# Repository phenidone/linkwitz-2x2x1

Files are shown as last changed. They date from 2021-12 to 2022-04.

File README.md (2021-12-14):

# Linkwitz (2x2).1

This is a PCB design for an analogue active crossover system.  It implements the basic set of active filters required
to build a 2.1 speaker system with 2-way main speakers and a single subwoofer.

The board fits in the standard/cheap 100x100mm PCB-prototyping form-factor.  It is mostly surface-mount, except it supports 
DIP op-amps and provides through-hole options for the larger capacitors.

## Filtering

The board implements:
* Input filtering and buffered stereo volume control
* A subwoofer signal chain, composed of:
  * Channel mixer
  * Plugin port for an external filter, e.g. room-correction notch
  * Linkwitz Transform
  * 2nd-order Butterworth subsonic filter
  * 4th-order Linkwitz-Riley low-pass
  * Gain control pot
* A midrange signal chain for each channel, composed of:
  * Plugin port for an external baffle-step compensation filter
  * 4th-order Linkwitz-Riley high-pass
  * 4th-order Linkwitz-Riley low-pass
  * Gain control trimpot
* A tweeter signal chain for each channel, composed of:
  * 4th-order Linkwitz-Riley high-pass
  * Plugin port for an external all-pass filter
  * Gain control trimpot

Room measurements will be necessary before performing component selection on the Linkwitz Transform.

## I/O

The board accepts a stereo line-level signal and produces 5 line level signals:
* Subwoofer
* Left mid-woofer
* Right mid-woofer
* Left tweeter
* Right tweeter

## Power

The board requires a dual-rail regulated DC supply, 12-15V.  Use screw terminals.

## Components

You will need 13 dual op-amp DIPs, probably NE5532.  You can use TL072 for the subwoofer chain, particularly if you need to 
save power and/or are building relatively high-impedance Linkwitz-Transform and Subsonic Filters because you couldn't find 
large enough capacitors...

Filter capacitors should be film type, with surface-mount capacitors intended to be polyphenylene sulfide (PPS) e.g. 
Panasonic ECHU(X), with at most 2% tolerance.  Filter resistors should be thin-film metal with 1% or better tolerance, 
though thick-film metal resistors are acceptable in the subwoofer section outside the filters.

Bypass capacitors are X7R ceramic, the main filter caps at the power port can be tantalum or electrolytic and as large as 
you like as long as they fit.

All surface-mount resistors and non-filter capacitors are 0805 footprint.  Filter capacitors are multi-footprint, with 
1210/1206 for most and through-hole lead-pitch options between 5mm and 15mm for the larger ones where MKT/PP/PET 
rectangular types will be required.  In some cases, up to 3 footprints are provided in series/parallel to allow you to make 
up precise values by combination; 0R bridges will be required to fill in unused resistor footprints.

## TRL and Regulatory

This design has been prototyped and unit-tested as working in a benign environment.  It has not faced MTBF validation 
or environmental (thermal+vibration) testing.

This is a PELV (Protected Extra Low Voltage, per IEC-60950) circuit, which should remain safe except in cases of a ground 
fault in the power supply external to this PCB.  Similarly, this is a low-frequency audio application with no switching 
power supplies and no clocks, therefore there are believed to be no regulatory requirements relating to EMI in most 
jurisdictions.  It has received no third-party certification or testing.

## License

This hardware design is (C) 2021 William Brodie-Tyrrell and is licensed under the CERN OHL; see cern_ohl_v_1_2.pdf

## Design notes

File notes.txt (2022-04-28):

Linkwitz-Riley rules:
f = 1/(2^1.5 pi R C)
R = 1/(2^1.5 pi f C)

lowpass uses 4R and 6C, 2x1u
highpass uses 6R and 4C, 2x1u
... channel.
Total 20R and 20C for stereo slope-pair

for bookshelves:
100Hz: 100n and 11253, 12k=94Hz, 11k=102Hz
75Hz: 100n and 15k
63Hz: 100n and 18k *
47Hz: 100n and 24k
2000Hz: 22n and 2550R/2490R *

Linkwitz Transform
31Hz, Q=0.707 to 20Hz, Q=0.73

THIS ONE:
R1=13.4k = 12k+1.2k+220
R2=45.6k = 39k+5.6k+1k
R3=32.1k = 27k+4.7k+390
C1=1.48u = 1.5u
C2=100n, 2 of
C3=615n = 560n+47n+10n

2nd order Butterworth for LF highpass...
for 15Hz corner
C=200n, R=39k (14Hz)
C=560n, R=12k (17Hz)
needs 2 of C and 3 of R

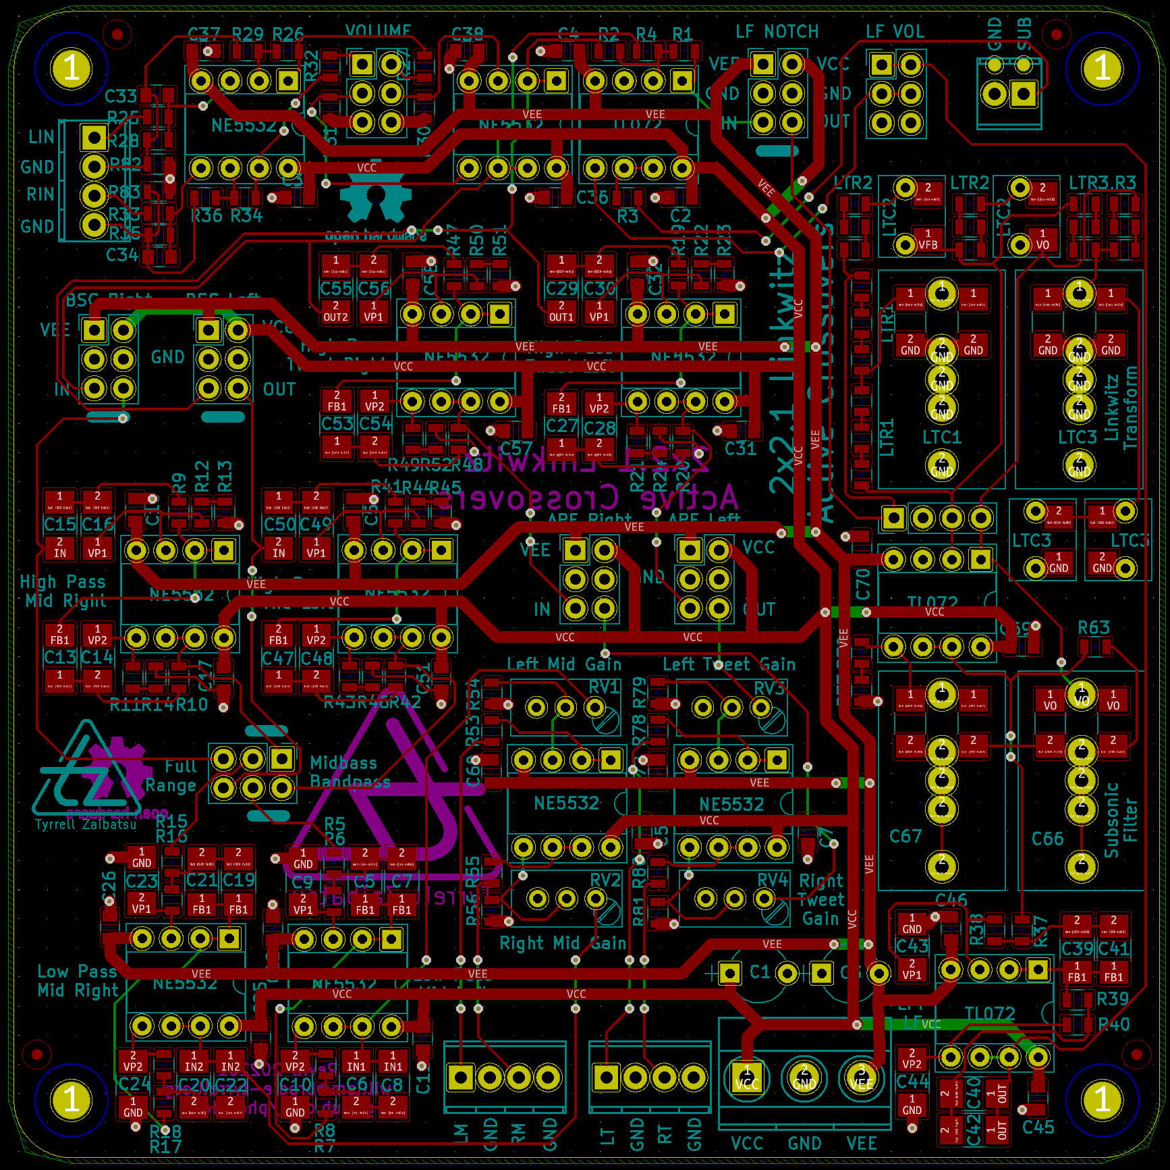
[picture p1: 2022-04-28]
xover-layout.png

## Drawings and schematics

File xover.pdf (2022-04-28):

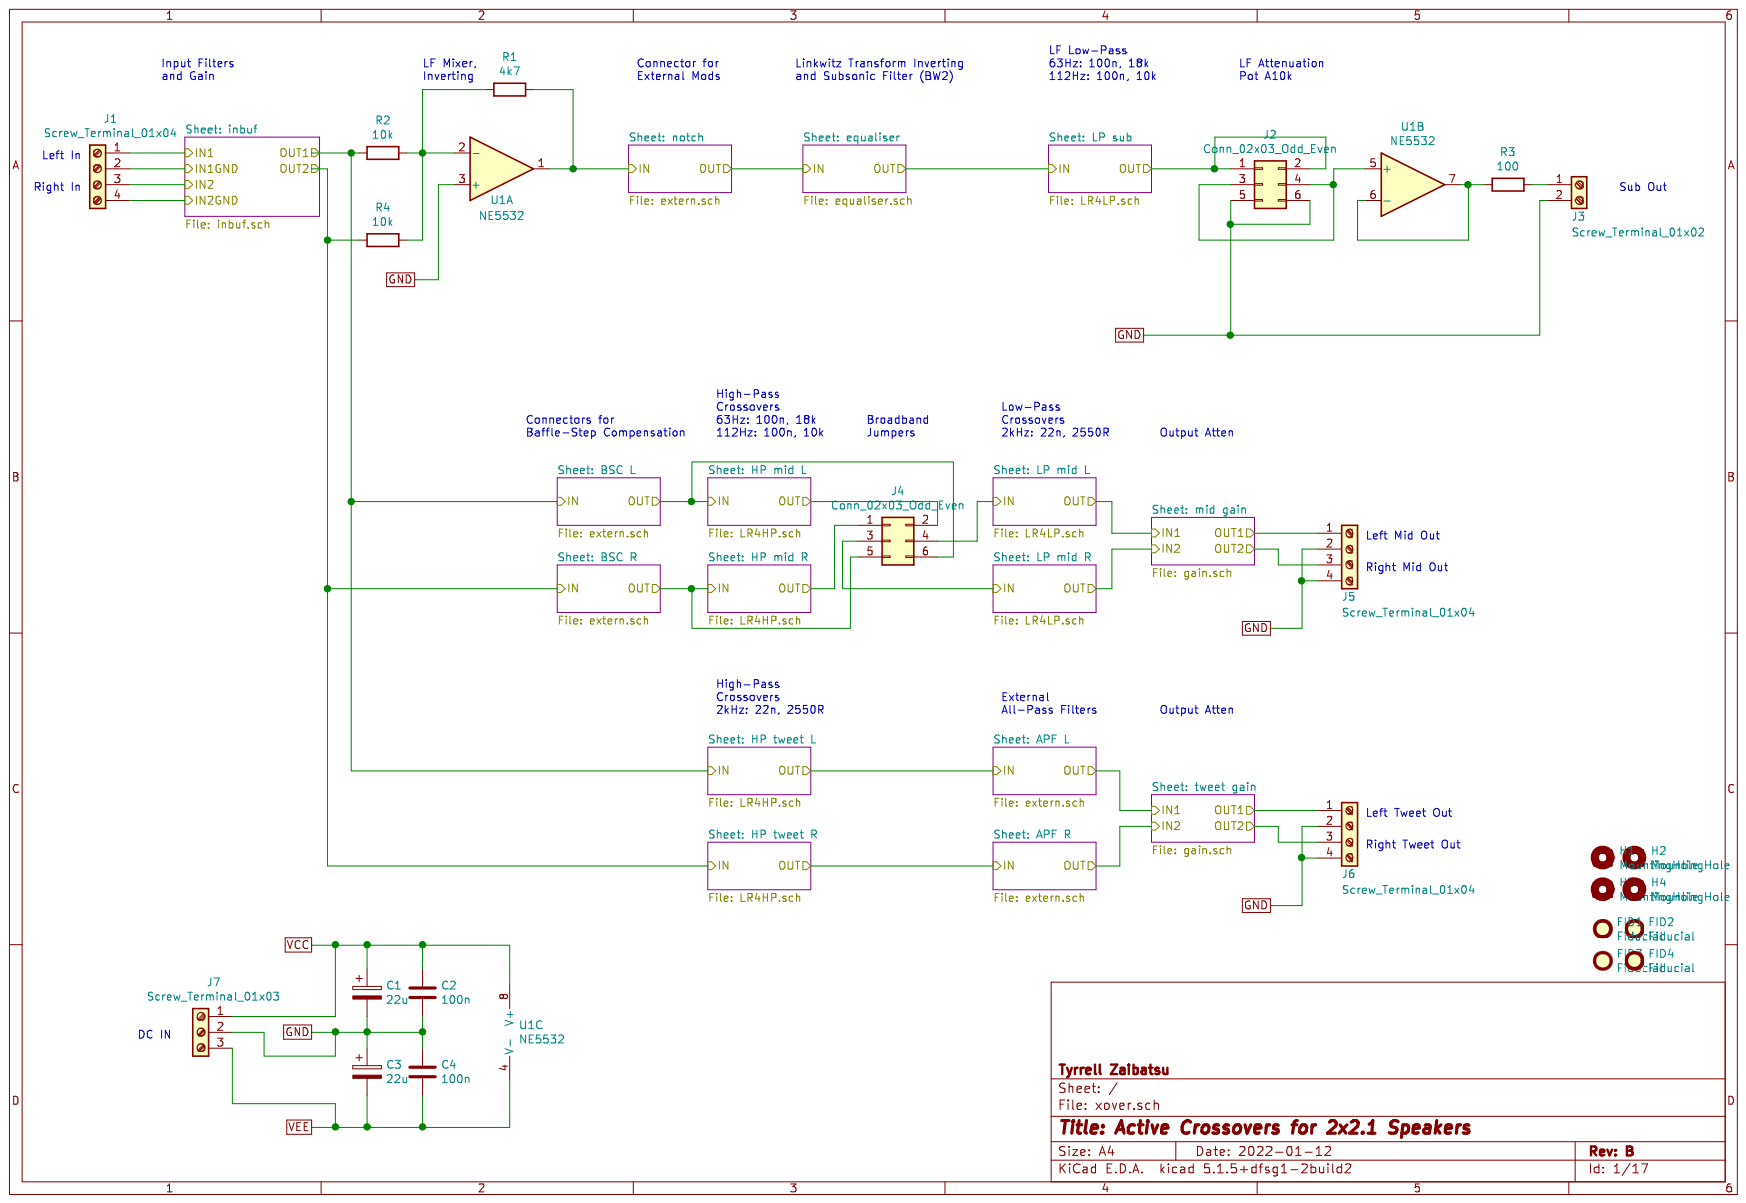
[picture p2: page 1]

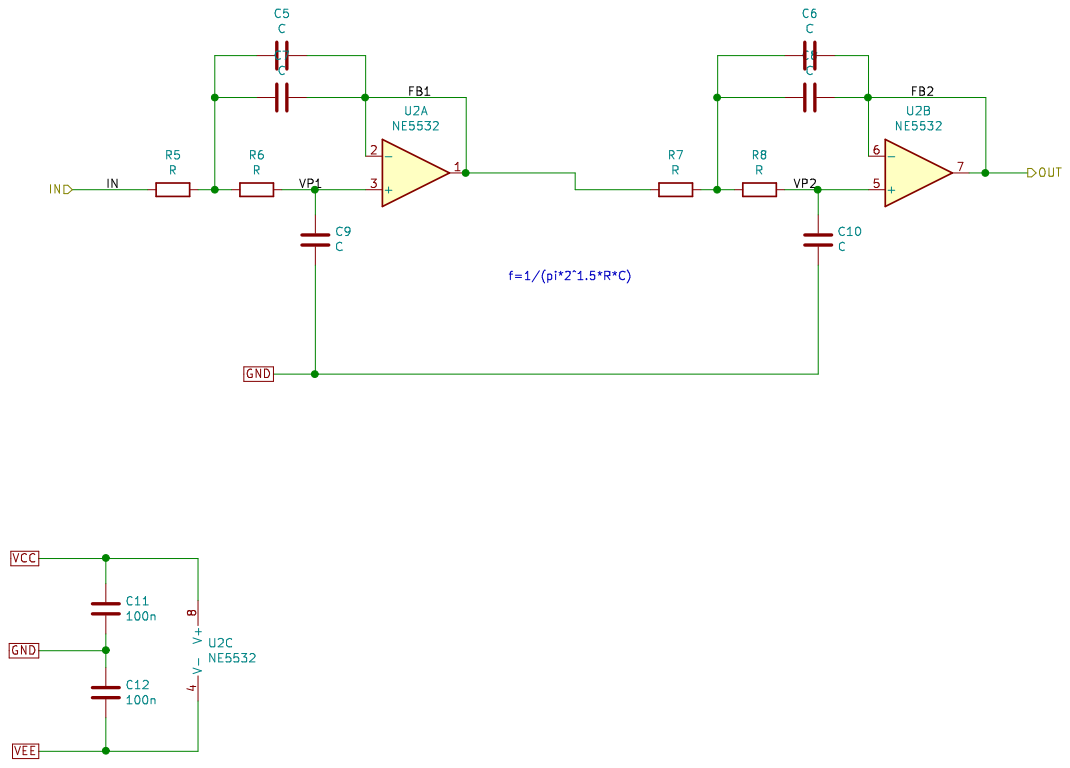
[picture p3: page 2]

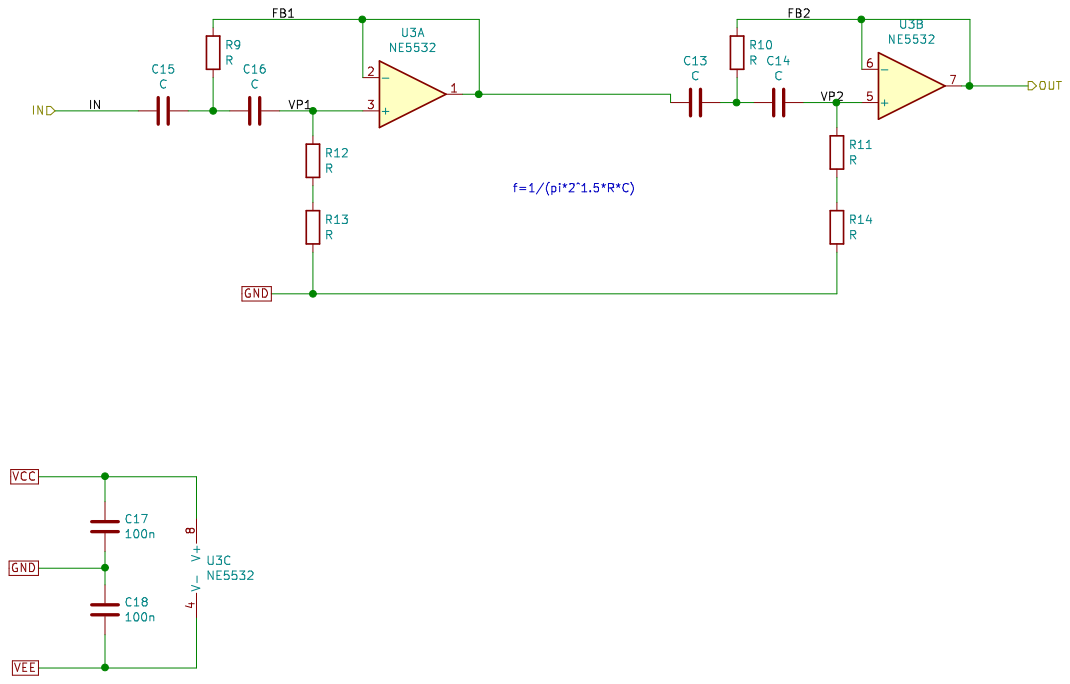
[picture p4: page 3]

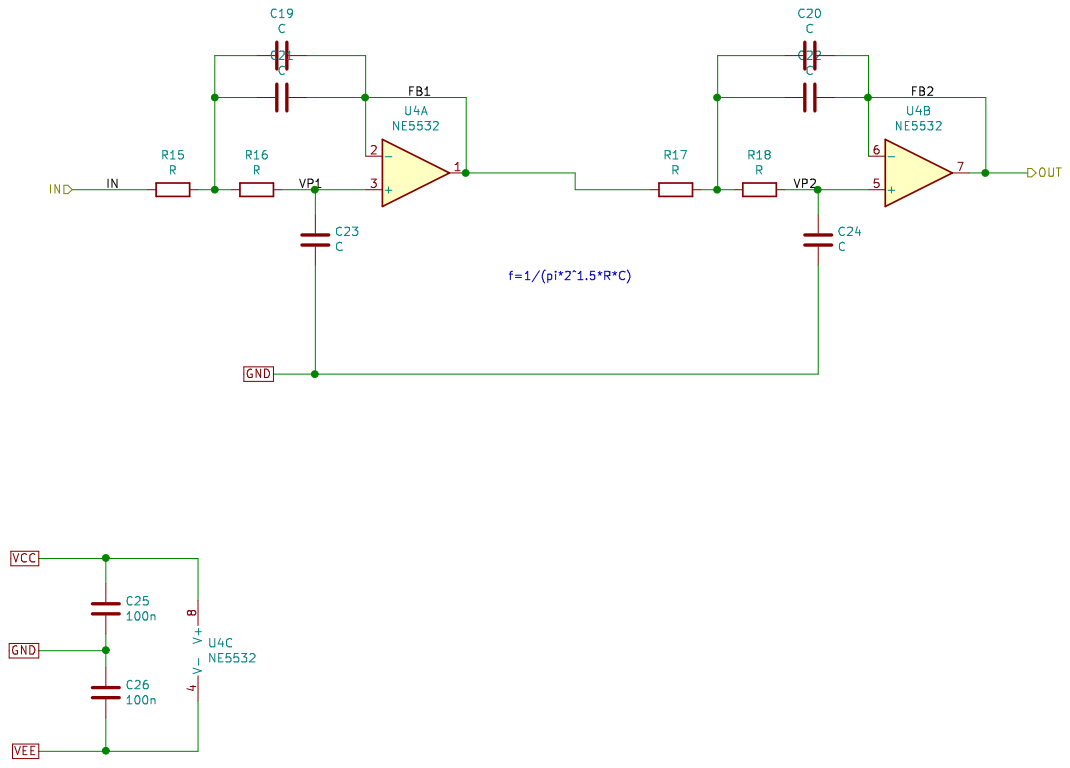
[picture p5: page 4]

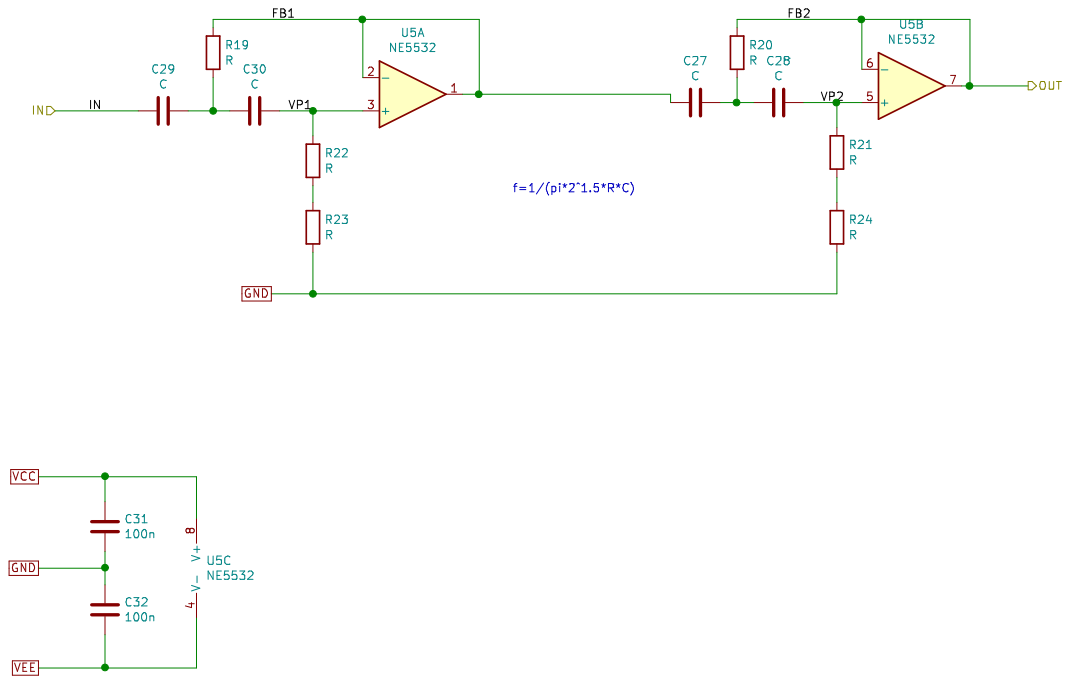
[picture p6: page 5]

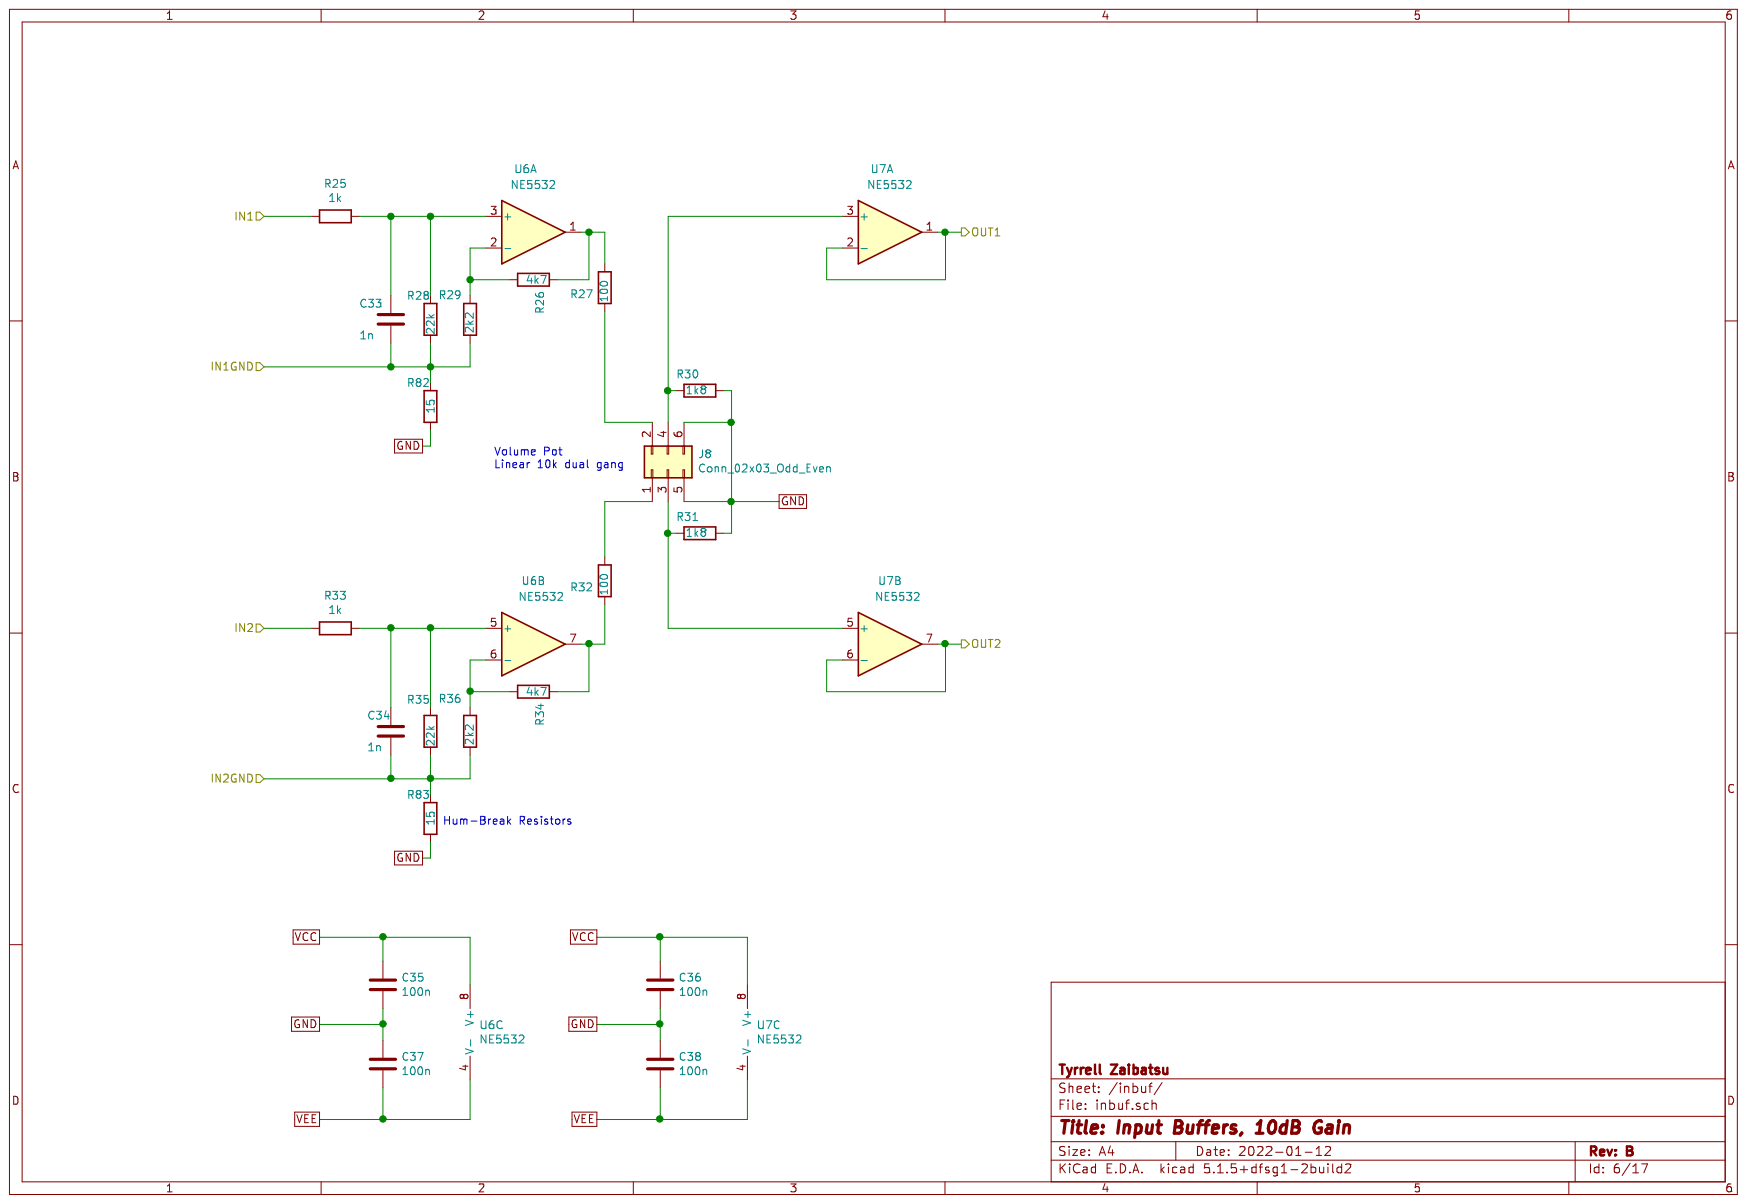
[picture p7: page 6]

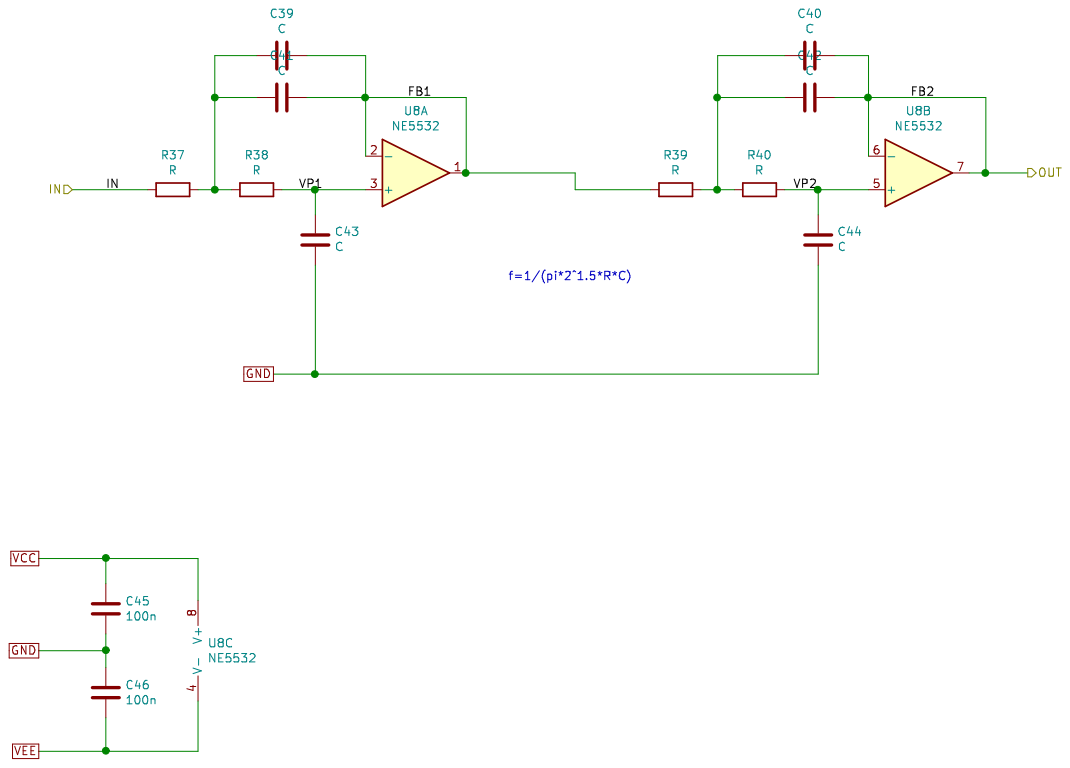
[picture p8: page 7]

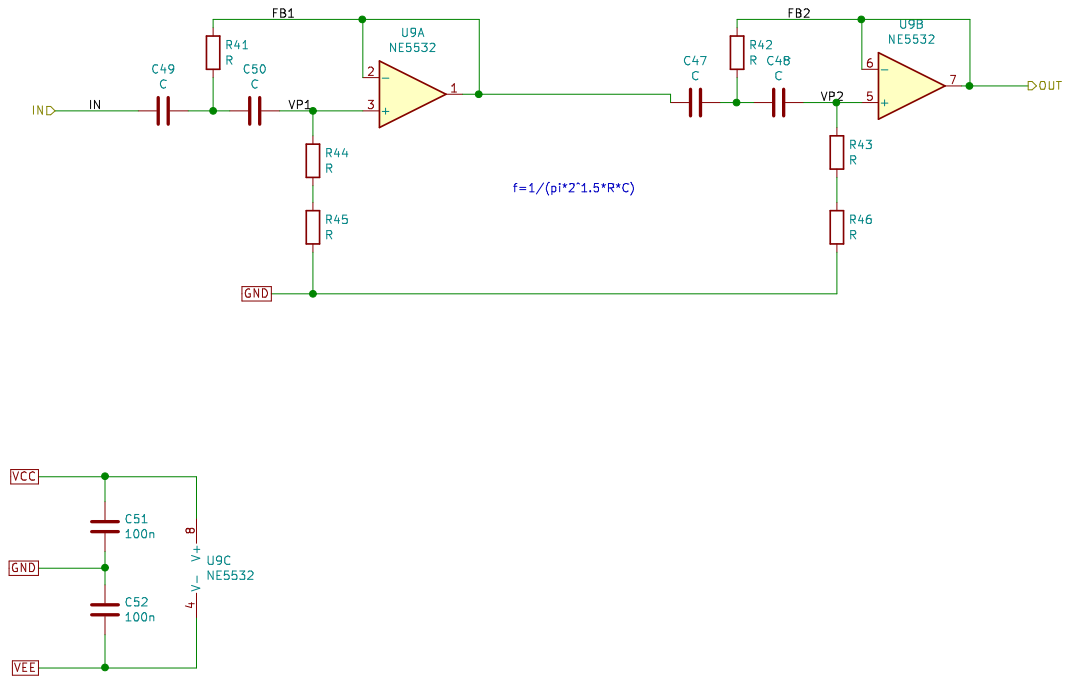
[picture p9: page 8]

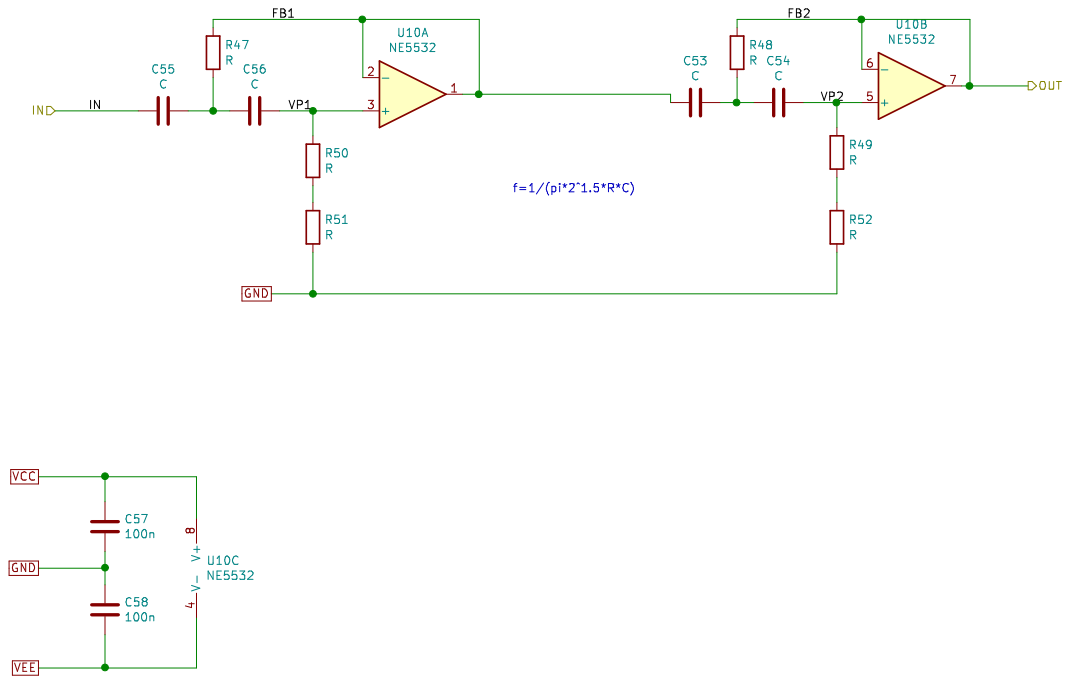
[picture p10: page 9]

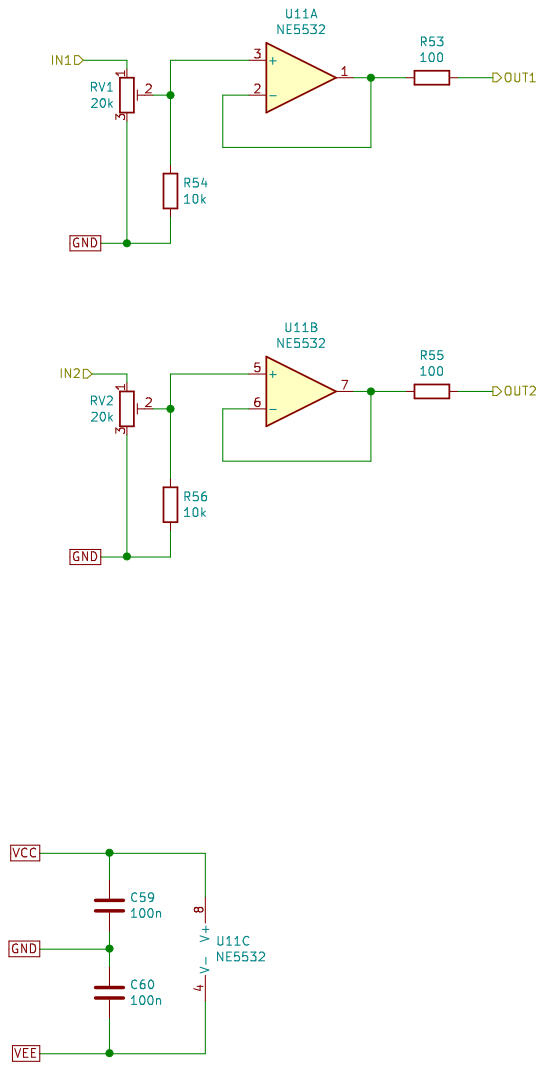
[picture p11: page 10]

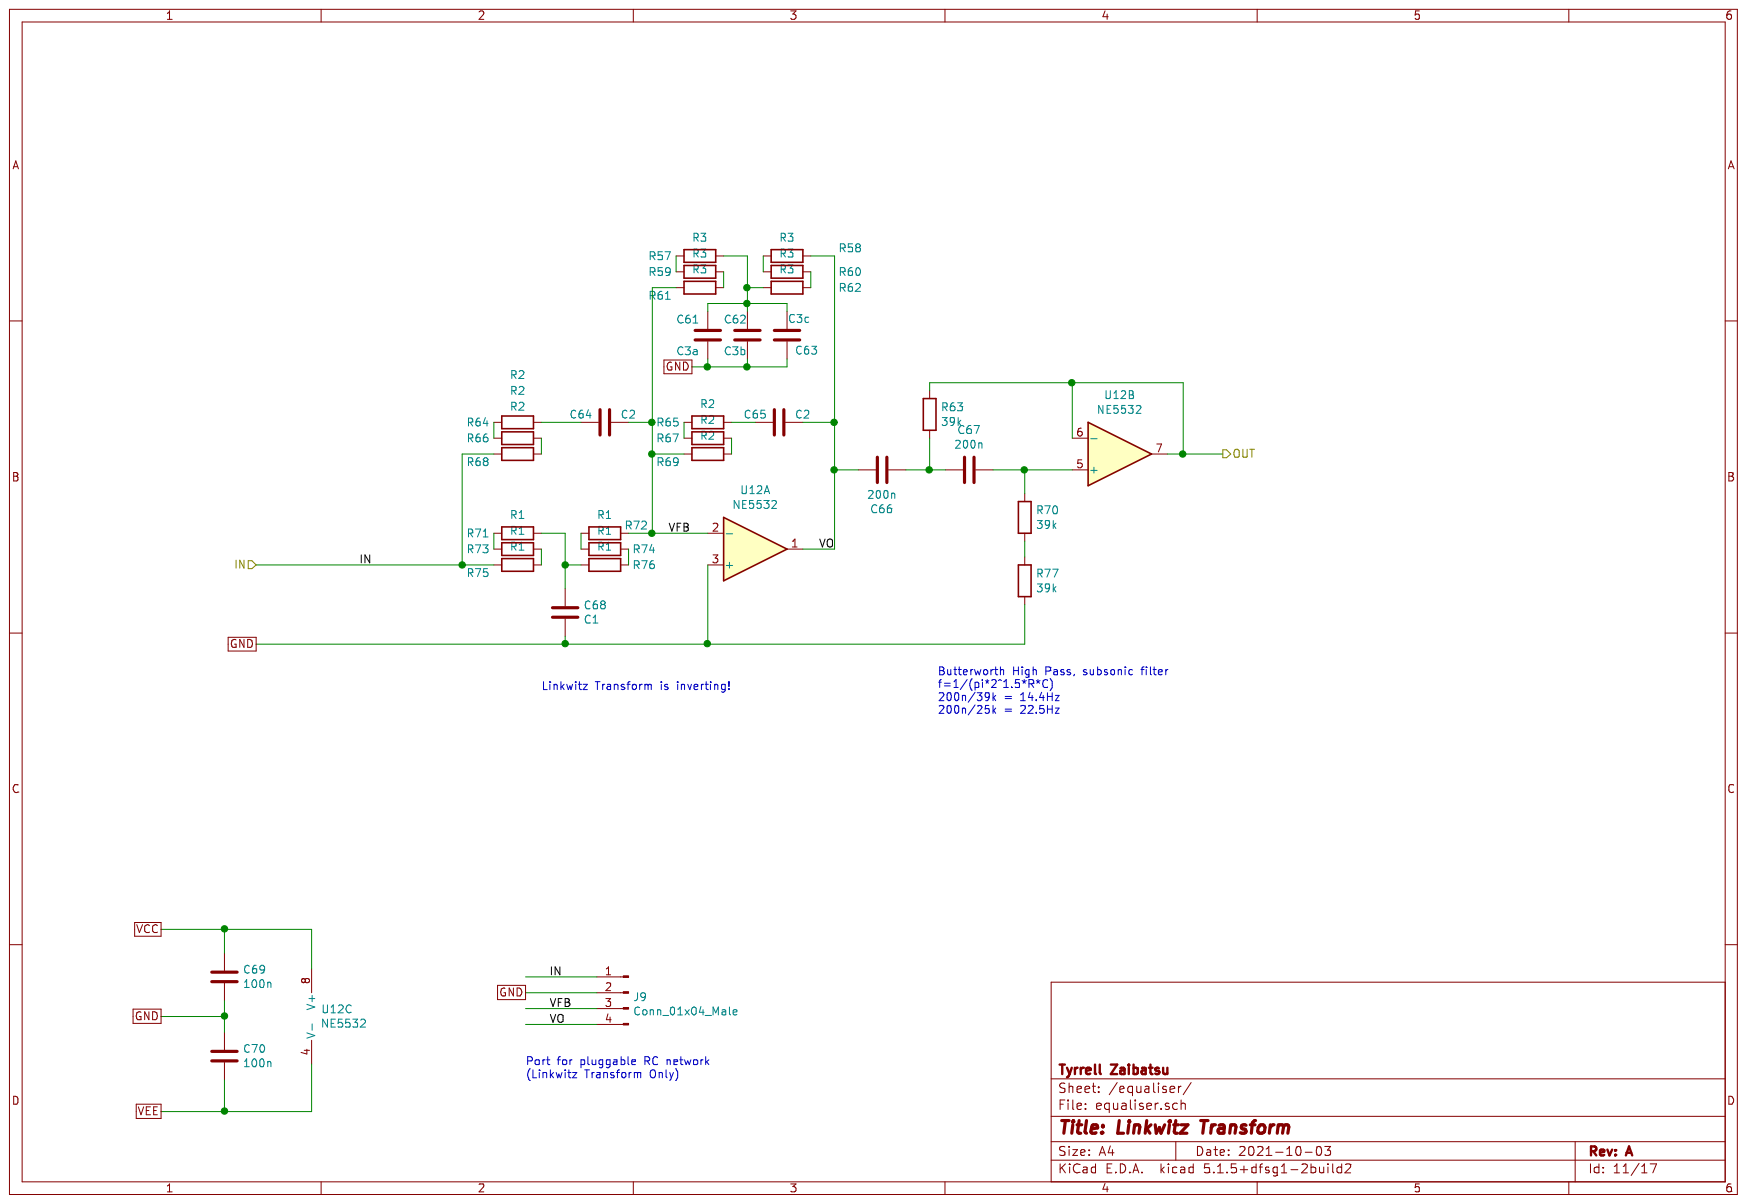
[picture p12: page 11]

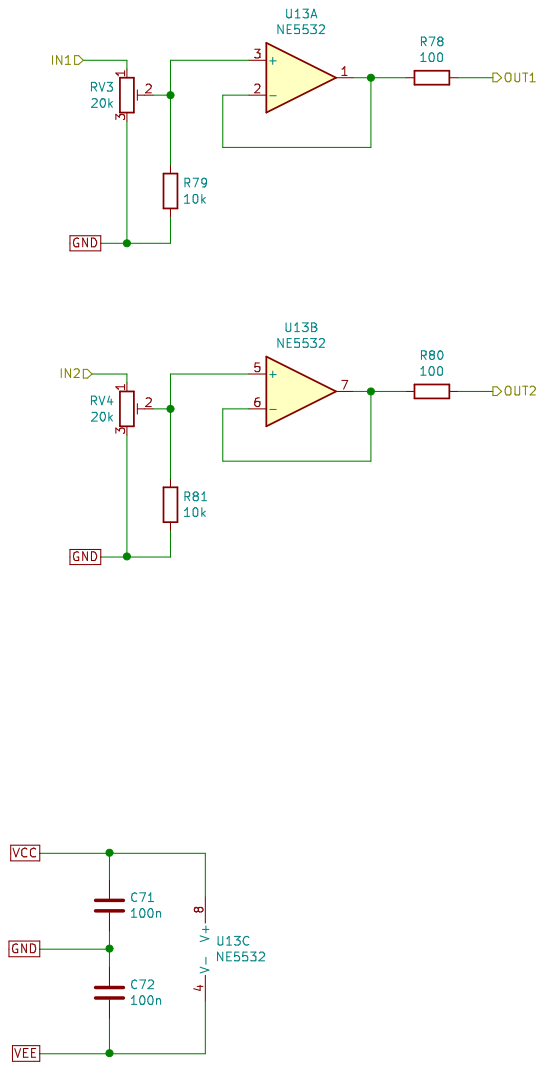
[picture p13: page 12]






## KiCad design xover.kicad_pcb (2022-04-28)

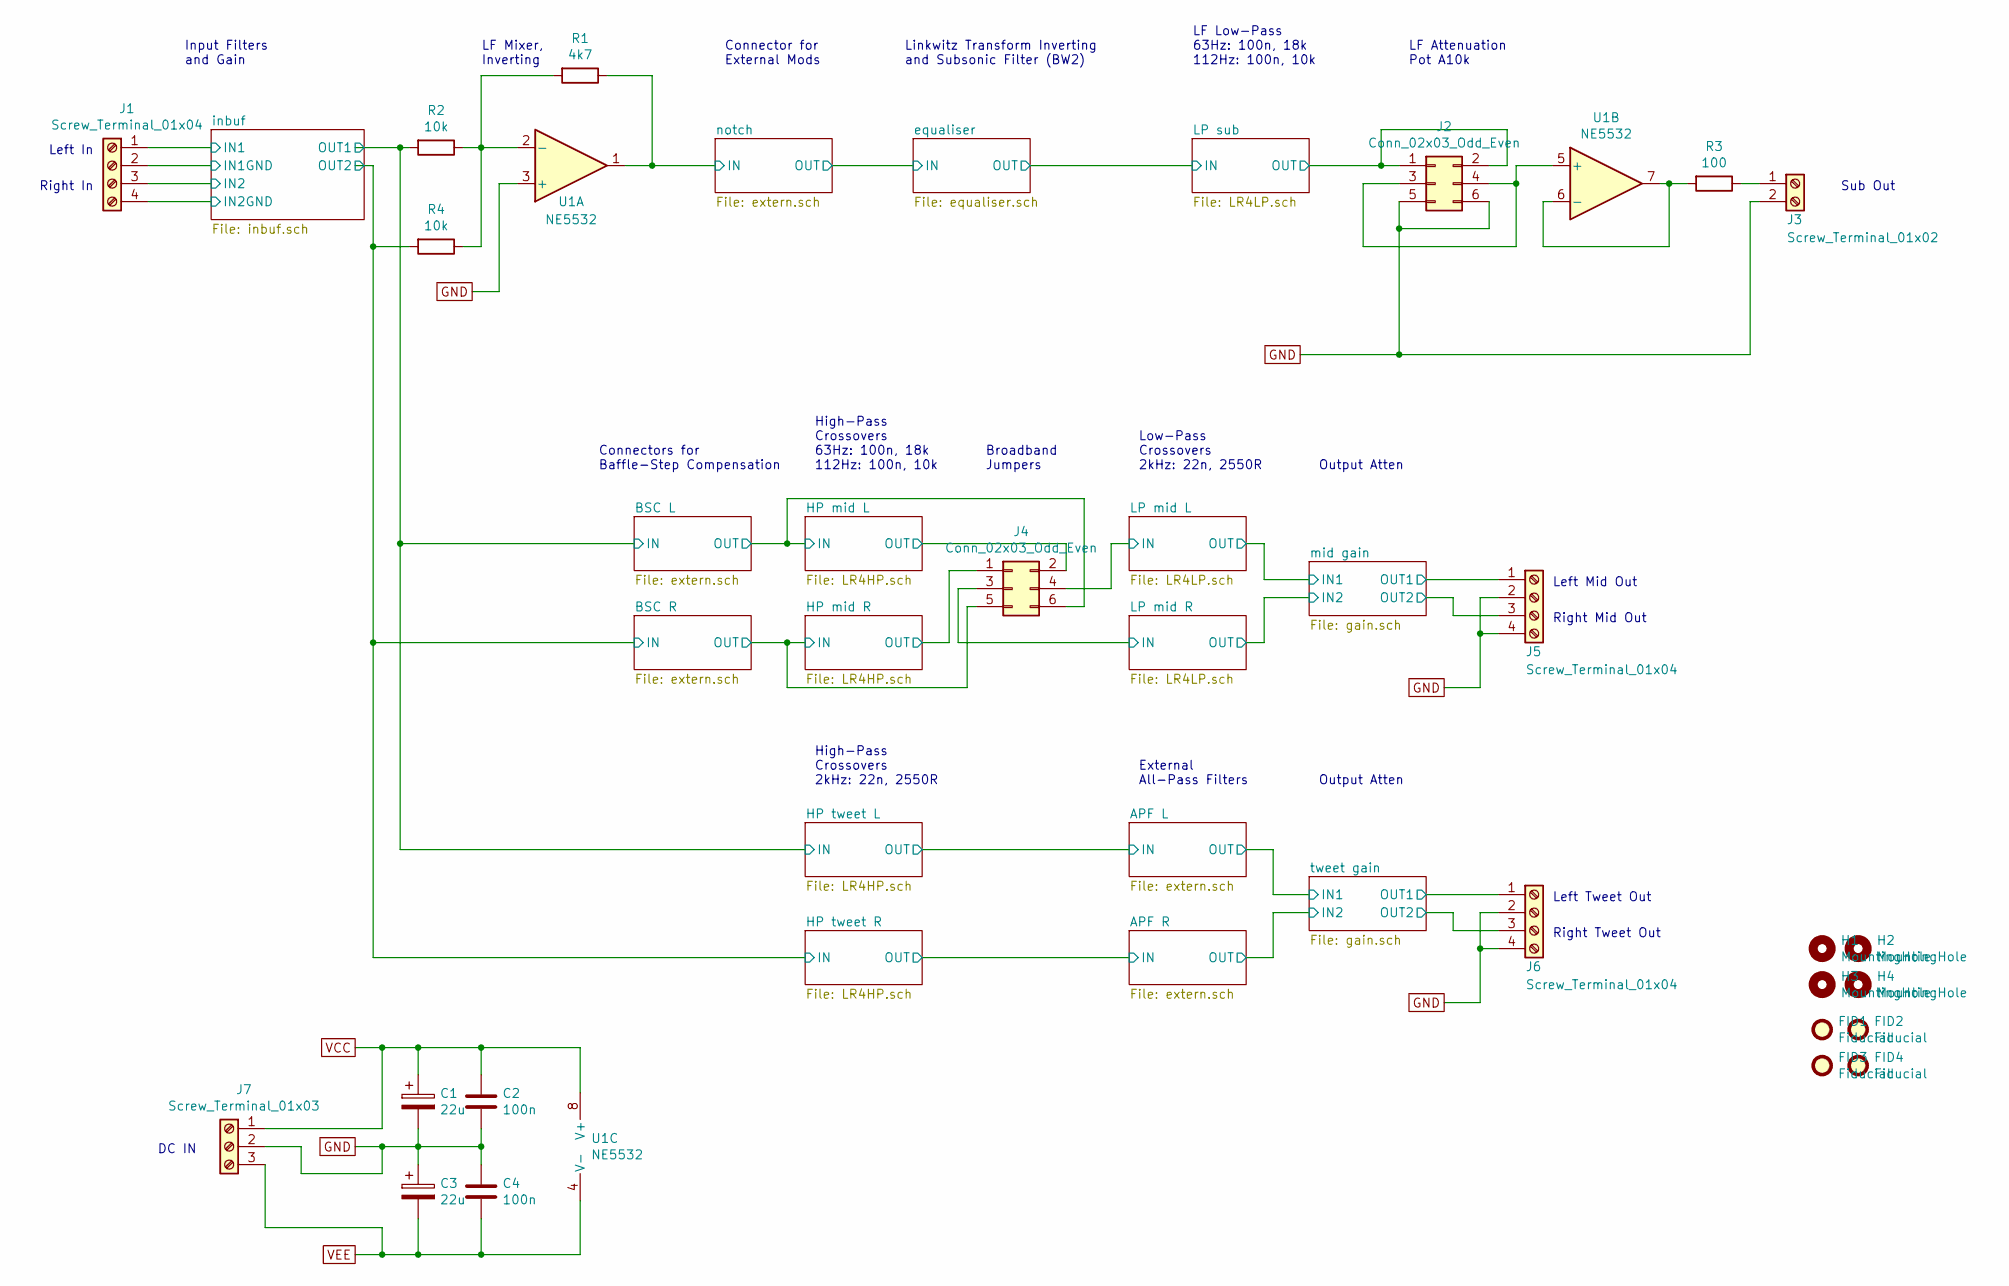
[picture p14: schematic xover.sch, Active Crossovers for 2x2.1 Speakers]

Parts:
C1, C3: 22u; CP_Radial_Tantal_D5.0mm_P5.00mm
C2, C4: 100n; C_0805
FID1, FID2, FID3, FID4: Fiducial; Fiducial_1mm_Dia_2.54mm_Outer_CopperTop
H1, H2, H3, H4: MountingHole; MountingHole_3.2mm_M3
J1, J5, J6: Screw_Terminal_01x04; TerminalBlock_Phoenix_MPT-2.54mm_4pol
J2, J4: Conn_02x03_Odd_Even; Pin_Header_Straight_2x03_Pitch2.54mm
J3: Screw_Terminal_01x02; TerminalBlock_Phoenix_MPT-2.54mm_2pol
J7: Screw_Terminal_01x03; TerminalBlock_Phoenix_MKDS1.5-3pol
R1: 4k7; R_0805
R2, R4: 10k; R_0805
R3: 100; R_0805
U1: NE5532; DIP-8_W7.62mm_Socket

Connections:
/HP mid L/IN: J4.6; also elsewhere on the board
/HP mid L/OUT: J4.2; also elsewhere on the board
/HP mid R/IN: J4.5; also elsewhere on the board
/HP mid R/OUT: J4.1; also elsewhere on the board
/LP mid L/IN: J4.4; also elsewhere on the board
/LP mid R/IN: J4.3; also elsewhere on the board
/LP sub/OUT: J2.1, J2.2; also elsewhere on the board
/inbuf/IN1: J1.1; also elsewhere on the board
/inbuf/IN1GND: J1.2; also elsewhere on the board
/inbuf/IN2: J1.3; also elsewhere on the board
/inbuf/IN2GND: J1.4; also elsewhere on the board
/inbuf/OUT1: R2.2; also elsewhere on the board
/inbuf/OUT2: R4.2; also elsewhere on the board
/mid gain/OUT1: J5.1; also elsewhere on the board
/mid gain/OUT2: J5.3; also elsewhere on the board
/notch/IN: R1.1, U1.1; also elsewhere on the board
/tweet gain/OUT1: J6.1; also elsewhere on the board
/tweet gain/OUT2: J6.3; also elsewhere on the board
GND: C1.2, C2.2, C3.1, C4.1, J2.5, J2.6, J3.2, J5.2, J5.4, J6.2, J6.4, J7.2, U1.3 (+); also elsewhere on the board
unnamed: J2.3, J2.4, U1.5 (+)
unnamed: J3.1, R3.1
unnamed: R1.2, R2.1, R4.1, U1.2 (-)
unnamed: R3.2, U1.6 (-), U1.7
VCC: C1.1, C2.1, J7.1, U1.8 (V+); also elsewhere on the board
VEE: C3.2, C4.2, J7.3, U1.4 (V-); also elsewhere on the board

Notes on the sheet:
Broadband Jumpers
LF Mixer, Inverting
LF Low-Pass 63Hz: 100n, 18k 112Hz: 100n, 10k
Linkwitz Transform Inverting and Subsonic Filter (BW2)
Sub Out
Left Mid Out
Right Mid Out
Left In
Right In
Right Tweet Out
Left Tweet Out
Input Filters and Gain
External All-Pass Filters
Connectors for Baffle-Step Compensation
High-Pass Crossovers 63Hz: 100n, 18k 112Hz: 100n, 10k
Low-Pass Crossovers 2kHz: 22n, 2550R
Output Atten
High-Pass Crossovers 2kHz: 22n, 2550R
LF Attenuation Pot A10k
DC IN
Connector for External Mods

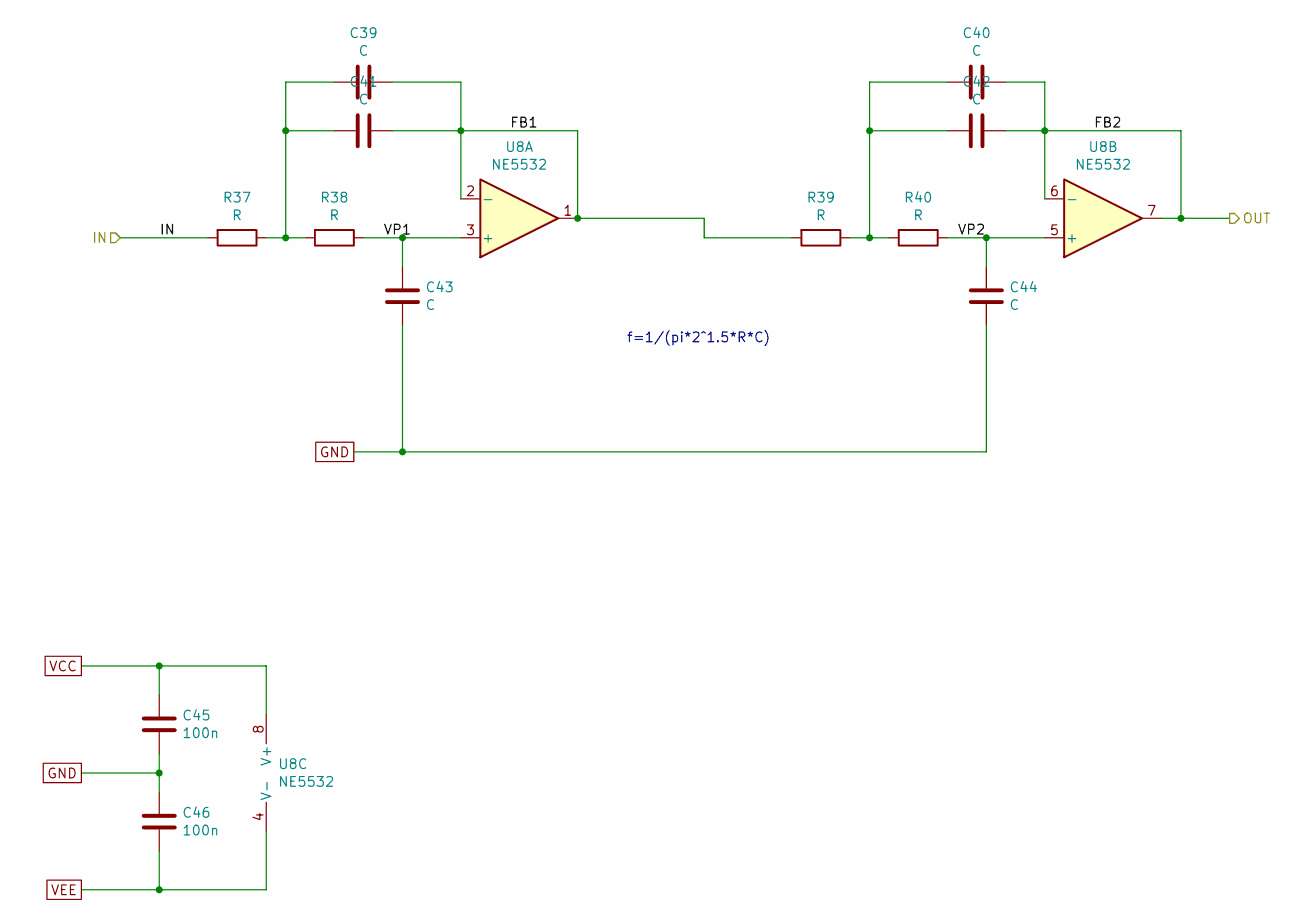
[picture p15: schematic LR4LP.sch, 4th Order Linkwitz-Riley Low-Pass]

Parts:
C5, C6, C7, C8, C9, C10: C; C_1210_HandSoldering
C11, C12: 100n; C_0805
R5, R6, R7, R8: R; R_0805
U2: NE5532; DIP-8_W7.62mm_Socket

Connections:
/LP mid L/FB1: C5.1, C7.1, R7.2, U2.1, U2.2 (-)
/LP mid L/IN: R5.2; also elsewhere on the board
/LP mid L/VP1: C9.2, R6.1, U2.3 (+)
/LP mid L/VP2: C10.2, R8.1, U2.5 (+)
/mid gain/IN1: C6.1, C8.1, U2.6 (-), U2.7; also elsewhere on the board
GND: C9.1, C10.1, C11.2, C12.1; also elsewhere on the board
unnamed: C5.2, C7.2, R5.1, R6.2
unnamed: C6.2, C8.2, R7.1, R8.2
VCC: C11.1, U2.8 (V+); also elsewhere on the board
VEE: C12.2, U2.4 (V-); also elsewhere on the board

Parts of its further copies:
C19, C20, C21, C22, C23, C24, C39, C40, C41, C42, C43, C44: C; C_1210_HandSoldering
C25, C26, C45, C46: 100n; C_0805
R15, R16, R17, R18, R37, R38, R39, R40: R; R_0805
U4, U8: NE5532; DIP-8_W7.62mm_Socket

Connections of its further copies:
/LP mid R/FB1: C19.1, C21.1, R17.2, U4.1, U4.2 (-)
/LP mid R/IN: R15.2; also elsewhere on the board
/LP mid R/VP1: C23.2, R16.1, U4.3 (+)
/LP mid R/VP2: C24.2, R18.1, U4.5 (+)
/LP sub/FB1: C39.1, C41.1, R39.2, U8.1, U8.2 (-)
/LP sub/IN: R37.2; also elsewhere on the board
/LP sub/OUT: C40.1, C42.1, U8.6 (-), U8.7; also elsewhere on the board
/LP sub/VP1: C43.2, R38.1, U8.3 (+)
/LP sub/VP2: C44.2, R40.1, U8.5 (+)
/mid gain/IN2: C20.1, C22.1, U4.6 (-), U4.7; also elsewhere on the board
GND: C23.1, C24.1, C25.2, C26.1, C43.1, C44.1, C45.2, C46.1; also elsewhere on the board
unnamed: C19.2, C21.2, R15.1, R16.2
unnamed: C20.2, C22.2, R17.1, R18.2
unnamed: C39.2, C41.2, R37.1, R38.2
unnamed: C40.2, C42.2, R39.1, R40.2
VCC: C25.1, C45.1, U4.8 (V+), U8.8 (V+); also elsewhere on the board
VEE: C26.2, C46.2, U4.4 (V-), U8.4 (V-); also elsewhere on the board

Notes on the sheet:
f=1/(pi*2^1.5*R*C)

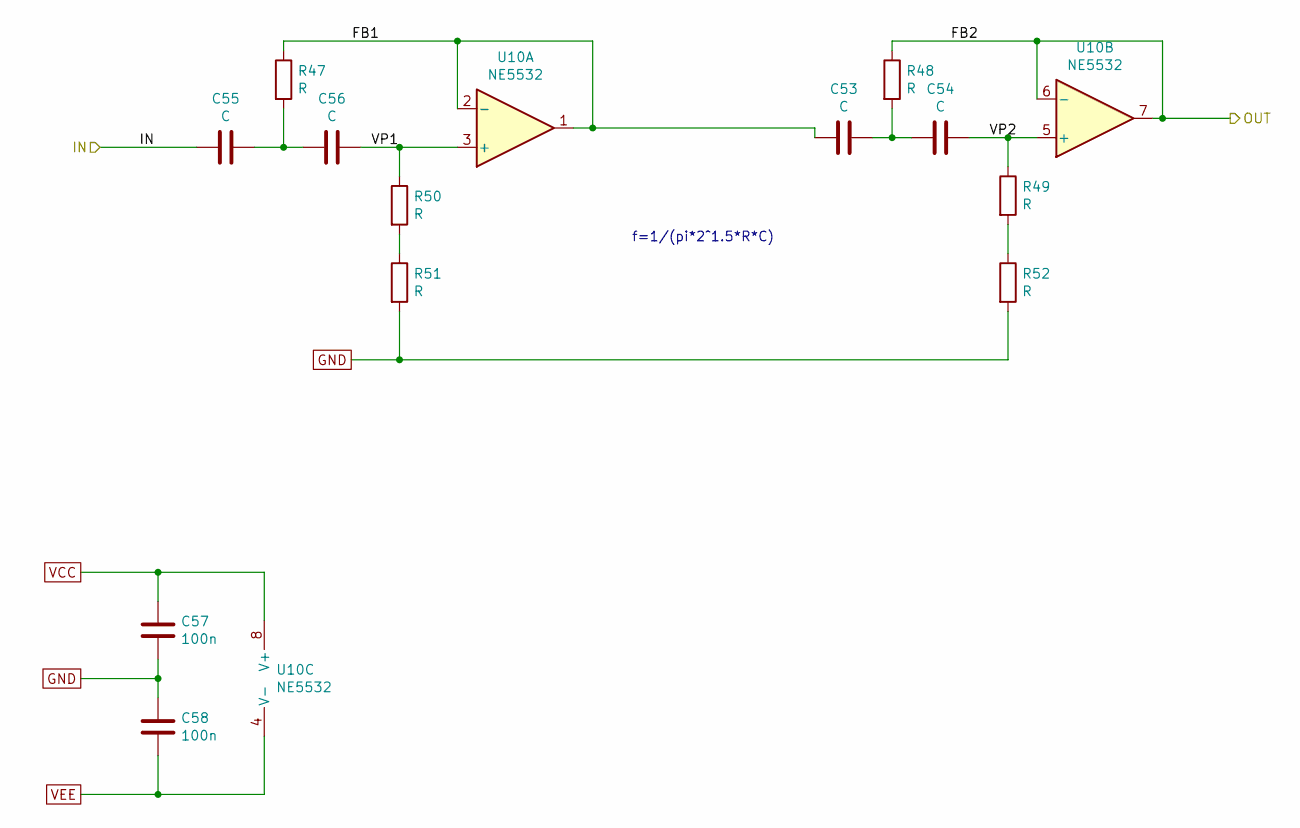
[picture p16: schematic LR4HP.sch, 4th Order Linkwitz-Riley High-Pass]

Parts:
C47, C48, C49, C50: C; C_1210_HandSoldering
C51, C52: 100n; C_0805
R41, R42, R43, R44, R45, R46: R; R_0805
U9: NE5532; DIP-8_W7.62mm_Socket

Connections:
/HP mid L/FB1: C47.2, R41.1, U9.1, U9.2 (-)
/HP mid L/IN: C49.2; also elsewhere on the board
/HP mid L/OUT: R42.1, U9.6 (-), U9.7; also elsewhere on the board
/HP mid L/VP1: C50.1, R44.1, U9.3 (+)
/HP mid L/VP2: C48.1, R43.1, U9.5 (+)
GND: C51.2, C52.1, R45.2, R46.2; also elsewhere on the board
unnamed: C47.1, C48.2, R42.2
unnamed: C49.1, C50.2, R41.2
unnamed: R43.2, R46.1
unnamed: R44.2, R45.1
VCC: C51.1, U9.8 (V+); also elsewhere on the board
VEE: C52.2, U9.4 (V-); also elsewhere on the board

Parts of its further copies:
C13, C14, C15, C16, C27, C28, C29, C30, C53, C54, C55, C56: C; C_1210_HandSoldering
C17, C18, C31, C32, C57, C58: 100n; C_0805
R9, R10, R11, R12, R13, R14, R19, R20, R21, R22, R23, R24, R47, R48, R49, R50, R51, R52: R; R_0805
U3, U5, U10: NE5532; DIP-8_W7.62mm_Socket

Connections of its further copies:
/APF L/IN: R20.1, U5.6 (-), U5.7; also elsewhere on the board
/APF R/IN: R48.1, U10.6 (-), U10.7; also elsewhere on the board
/HP mid R/FB1: C13.2, R9.1, U3.1, U3.2 (-)
/HP mid R/IN: C15.2; also elsewhere on the board
/HP mid R/OUT: R10.1, U3.6 (-), U3.7; also elsewhere on the board
/HP mid R/VP1: C16.1, R12.1, U3.3 (+)
/HP mid R/VP2: C14.1, R11.1, U3.5 (+)
/HP tweet L/FB1: C27.2, R19.1, U5.1, U5.2 (-)
/HP tweet L/VP1: C30.1, R22.1, U5.3 (+)
/HP tweet L/VP2: C28.1, R21.1, U5.5 (+)
/HP tweet R/FB1: C53.2, R47.1, U10.1, U10.2 (-)
/HP tweet R/VP1: C56.1, R50.1, U10.3 (+)
/HP tweet R/VP2: C54.1, R49.1, U10.5 (+)
/inbuf/OUT1: C29.2; also elsewhere on the board
/inbuf/OUT2: C55.2; also elsewhere on the board
GND: C17.2, C18.1, C31.2, C32.1, C57.2, C58.1, R13.2, R14.2, R23.2, R24.2, R51.2, R52.2; also elsewhere on the board
unnamed: C13.1, C14.2, R10.2
unnamed: C15.1, C16.2, R9.2
unnamed: C27.1, C28.2, R20.2
unnamed: C29.1, C30.2, R19.2
unnamed: C53.1, C54.2, R48.2
unnamed: C55.1, C56.2, R47.2
unnamed: R11.2, R14.1
unnamed: R12.2, R13.1
unnamed: R21.2, R24.1
unnamed: R22.2, R23.1
unnamed: R49.2, R52.1
unnamed: R50.2, R51.1
VCC: C17.1, C31.1, C57.1, U3.8 (V+), U5.8 (V+), U10.8 (V+); also elsewhere on the board
VEE: C18.2, C32.2, C58.2, U3.4 (V-), U5.4 (V-), U10.4 (V-); also elsewhere on the board

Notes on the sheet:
f=1/(pi*2^1.5*R*C)

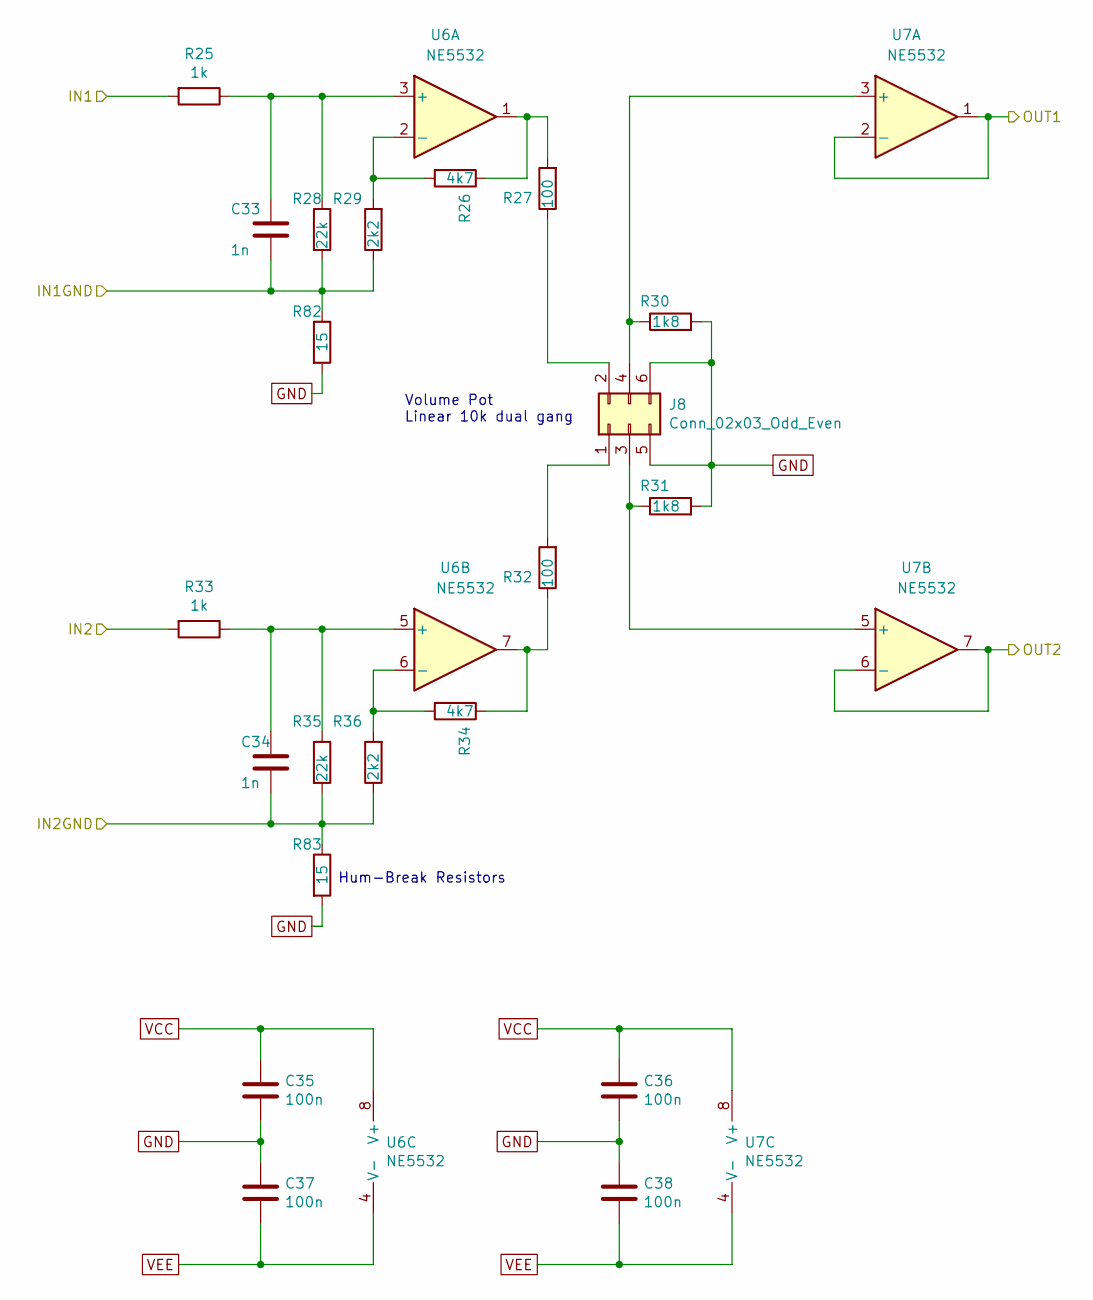
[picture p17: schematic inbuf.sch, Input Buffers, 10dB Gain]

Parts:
C33, C34: 1n; C_0805
C35, C36, C37, C38: 100n; C_0805
J8: Conn_02x03_Odd_Even; Pin_Header_Straight_2x03_Pitch2.54mm
R25, R33: 1k; R_0805
R26, R34: 4k7; R_0805
R27, R32: 100; R_0805
R28, R35: 22k; R_0805
R29, R36: 2k2; R_0805
R30, R31: 1k8; R_0805
R82, R83: 15; R_0805
U6, U7: NE5532; DIP-8_W7.62mm_Socket

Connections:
/inbuf/IN1: R25.2; also elsewhere on the board
/inbuf/IN1GND: C33.2, R28.2, R29.1, R82.1; also elsewhere on the board
/inbuf/IN2: R33.2; also elsewhere on the board
/inbuf/IN2GND: C34.2, R35.2, R36.1, R83.1; also elsewhere on the board
/inbuf/OUT1: U7.1, U7.2 (-); also elsewhere on the board
/inbuf/OUT2: U7.6 (-), U7.7; also elsewhere on the board
GND: C35.2, C36.2, C37.1, C38.1, J8.5, J8.6, R30.2, R31.2, R82.2, R83.2; also elsewhere on the board
unnamed: C33.1, R25.1, R28.1, U6.3 (+)
unnamed: C34.1, R33.1, R35.1, U6.5 (+)
unnamed: J8.1, R32.2
unnamed: J8.2, R27.1
unnamed: J8.3, R31.1, U7.5 (+)
unnamed: J8.4, R30.1, U7.3 (+)
unnamed: R26.1, R27.2, U6.1
unnamed: R26.2, R29.2, U6.2 (-)
unnamed: R32.1, R34.1, U6.7
unnamed: R34.2, R36.2, U6.6 (-)
VCC: C35.1, C36.1, U6.8 (V+), U7.8 (V+); also elsewhere on the board
VEE: C37.2, C38.2, U6.4 (V-), U7.4 (V-); also elsewhere on the board

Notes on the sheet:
Volume Pot Linear 10k dual gang
Hum-Break Resistors

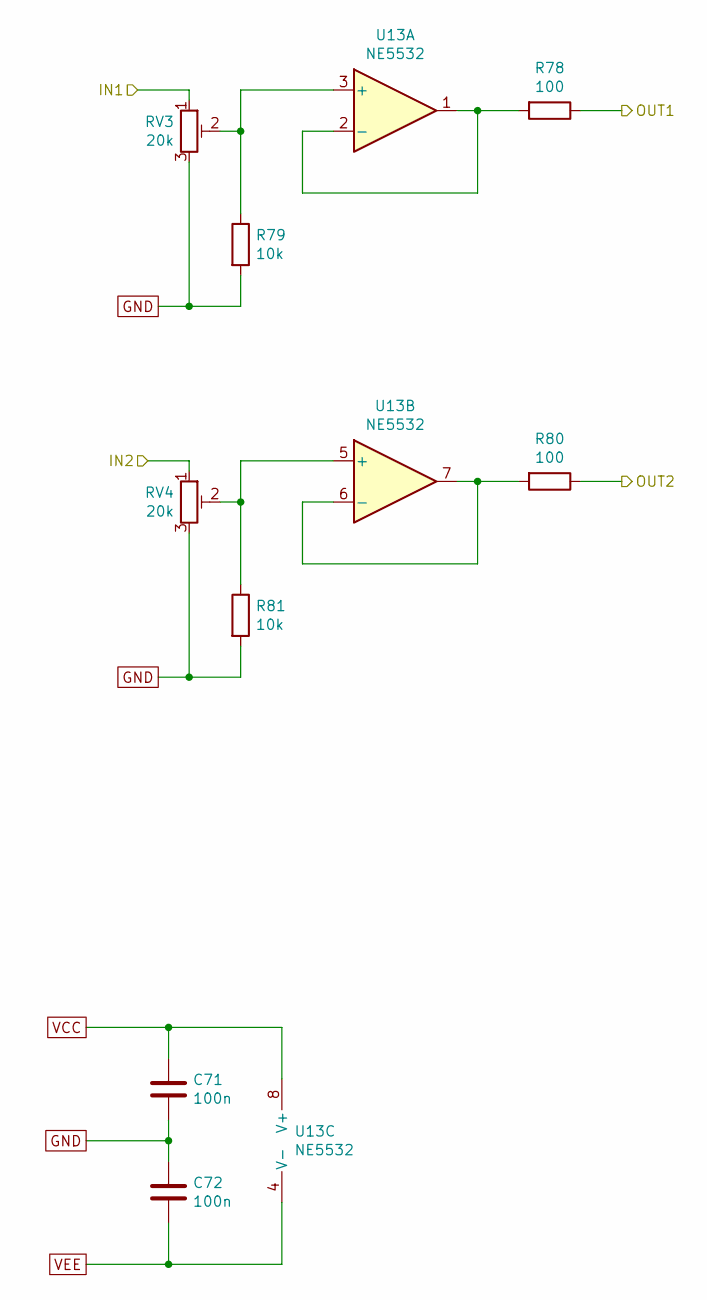
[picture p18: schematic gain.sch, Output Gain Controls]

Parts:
C59, C60: 100n; C_0805
R53, R55: 100; R_0805
R54, R56: 10k; R_0805
RV1, RV2: 20k; Potentiometer_Trimmer_Bourns_3296W
U11: NE5532; DIP-8_W7.62mm_Socket

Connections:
/mid gain/IN1: RV1.1; also elsewhere on the board
/mid gain/IN2: RV2.1; also elsewhere on the board
/mid gain/OUT1: R53.1; also elsewhere on the board
/mid gain/OUT2: R55.1; also elsewhere on the board
GND: C59.2, C60.1, R54.2, R56.2, RV1.3, RV2.3; also elsewhere on the board
unnamed: R53.2, U11.1, U11.2 (-)
unnamed: R54.1, RV1.2, U11.3 (+)
unnamed: R55.2, U11.6 (-), U11.7
unnamed: R56.1, RV2.2, U11.5 (+)
VCC: C59.1, U11.8 (V+); also elsewhere on the board
VEE: C60.2, U11.4 (V-); also elsewhere on the board

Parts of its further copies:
C71, C72: 100n; C_0805
R78, R80: 100; R_0805
R79, R81: 10k; R_0805
RV3, RV4: 20k; Potentiometer_Trimmer_Bourns_3296W
U13: NE5532; DIP-8_W7.62mm_Socket

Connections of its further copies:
/tweet gain/IN1: RV3.1; also elsewhere on the board
/tweet gain/IN2: RV4.1; also elsewhere on the board
/tweet gain/OUT1: R78.1; also elsewhere on the board
/tweet gain/OUT2: R80.1; also elsewhere on the board
GND: C71.2, C72.1, R79.2, R81.2, RV3.3, RV4.3; also elsewhere on the board
unnamed: R78.2, U13.1, U13.2 (-)
unnamed: R79.1, RV3.2, U13.3 (+)
unnamed: R80.2, U13.6 (-), U13.7
unnamed: R81.1, RV4.2, U13.5 (+)
VCC: C71.1, U13.8 (V+); also elsewhere on the board
VEE: C72.2, U13.4 (V-); also elsewhere on the board

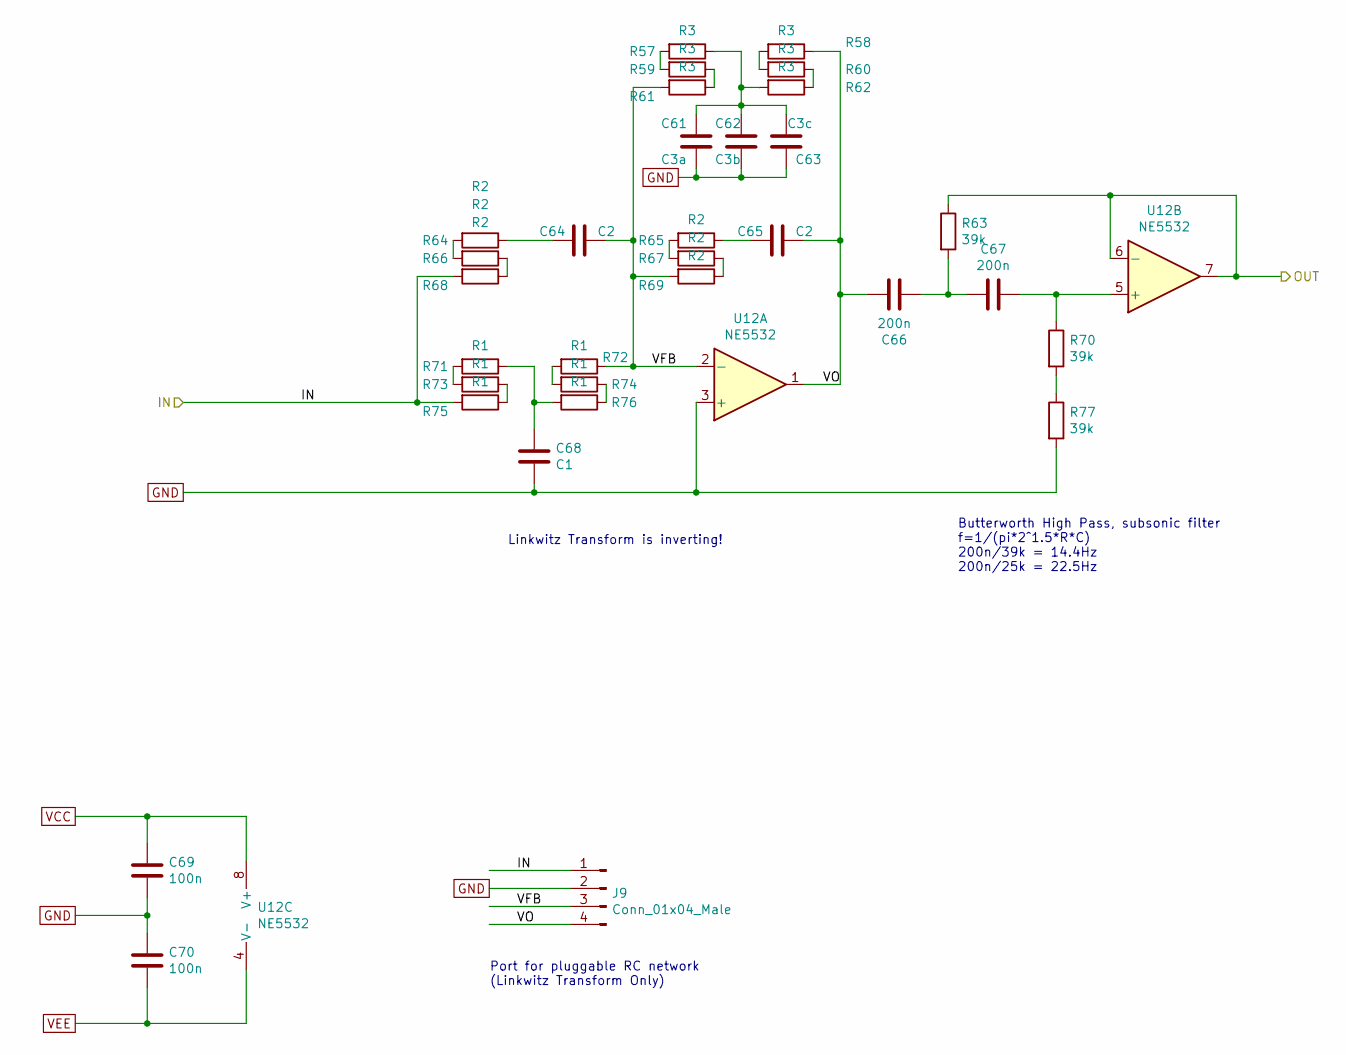
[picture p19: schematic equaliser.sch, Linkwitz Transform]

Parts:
C61: C3a; C_Rect_L19.0mm_W11.0mm_combo
C62: C3b; C_Rect_L7.0mm_W4.5mm_P5_1210_combo
C63: C3c; C_Rect_L7.0mm_W4.5mm_P5_1210_combo
C64, C65: C2; C_Rect_L7.0mm_W4.5mm_P5_1210_combo
C66, C67: 200n; C_Rect_L19.0mm_W11.0mm_combo
C68: C1; C_Rect_L19.0mm_W11.0mm_combo
C69, C70: 100n; C_0805
J9: Conn_01x04_Male; Pin_Header_Straight_1x04_Pitch2.54mm
R57, R58, R59, R60, R61, R62: R3; R_0805
R63, R70, R77: 39k; R_0805
R64, R65, R66, R67, R68, R69: R2; R_0805
R71, R72, R73, R74, R75, R76: R1; R_0805
U12: NE5532; DIP-8_W7.62mm_Socket

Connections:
/LP sub/IN: R63.1, U12.6 (-), U12.7; also elsewhere on the board
/equaliser/IN: J9.1, R68.2, R75.2; also elsewhere on the board
/equaliser/VFB: C64.1, J9.3, R61.2, R69.2, R72.1, U12.2 (-)
/equaliser/VO: C65.1, C66.1, J9.4, R58.1, U12.1
GND: C61.2, C62.2, C63.1, C68.2, C69.2, C70.1, J9.2, R77.2, U12.3 (+); also elsewhere on the board
unnamed: C61.1, C62.1, C63.2, R57.1, R62.2
unnamed: C64.2, R64.1
unnamed: C65.2, R65.1
unnamed: C66.2, C67.2, R63.2
unnamed: C67.1, R70.1, U12.5 (+)
unnamed: C68.1, R71.1, R76.2
unnamed: R57.2, R59.2
unnamed: R58.2, R60.2
unnamed: R59.1, R61.1
unnamed: R60.1, R62.1
unnamed: R64.2, R66.2
unnamed: R65.2, R67.2
unnamed: R66.1, R68.1
unnamed: R67.1, R69.1
unnamed: R70.2, R77.1
unnamed: R71.2, R73.2
unnamed: R72.2, R74.2
unnamed: R73.1, R75.1
unnamed: R74.1, R76.1
VCC: C69.1, U12.8 (V+); also elsewhere on the board
VEE: C70.2, U12.4 (V-); also elsewhere on the board

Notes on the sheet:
Linkwitz Transform is inverting!
Butterworth High Pass, subsonic filter f=1/(pi*2^1.5*R*C) 200n/39k = 14.4Hz 200n/25k = 22.5Hz
Port for pluggable RC network (Linkwitz Transform Only)

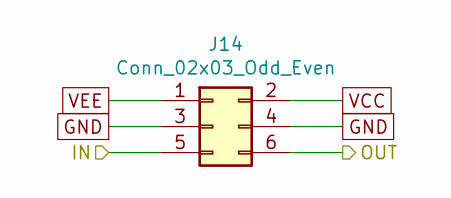
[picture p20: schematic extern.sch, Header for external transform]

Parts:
J10: Conn_02x03_Odd_Even; Pin_Header_Straight_2x03_Pitch2.54mm

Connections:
/APF L/IN: J10.5; also elsewhere on the board
/tweet gain/IN1: J10.6; also elsewhere on the board
GND: J10.3, J10.4; also elsewhere on the board
VCC: J10.2; also elsewhere on the board
VEE: J10.1; also elsewhere on the board

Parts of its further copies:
J11, J12, J13, J14: Conn_02x03_Odd_Even; Pin_Header_Straight_2x03_Pitch2.54mm

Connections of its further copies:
/APF R/IN: J11.5; also elsewhere on the board
/HP mid L/IN: J12.6; also elsewhere on the board
/HP mid R/IN: J13.6; also elsewhere on the board
/equaliser/IN: J14.6; also elsewhere on the board
/inbuf/OUT1: J12.5; also elsewhere on the board
/inbuf/OUT2: J13.5; also elsewhere on the board
/notch/IN: J14.5; also elsewhere on the board
/tweet gain/IN2: J11.6; also elsewhere on the board
GND: J11.3, J11.4, J12.3, J12.4, J13.3, J13.4, J14.3, J14.4; also elsewhere on the board
VCC: J11.2, J12.2, J13.2, J14.2; also elsewhere on the board
VEE: J11.1, J12.1, J13.1, J14.1; also elsewhere on the board

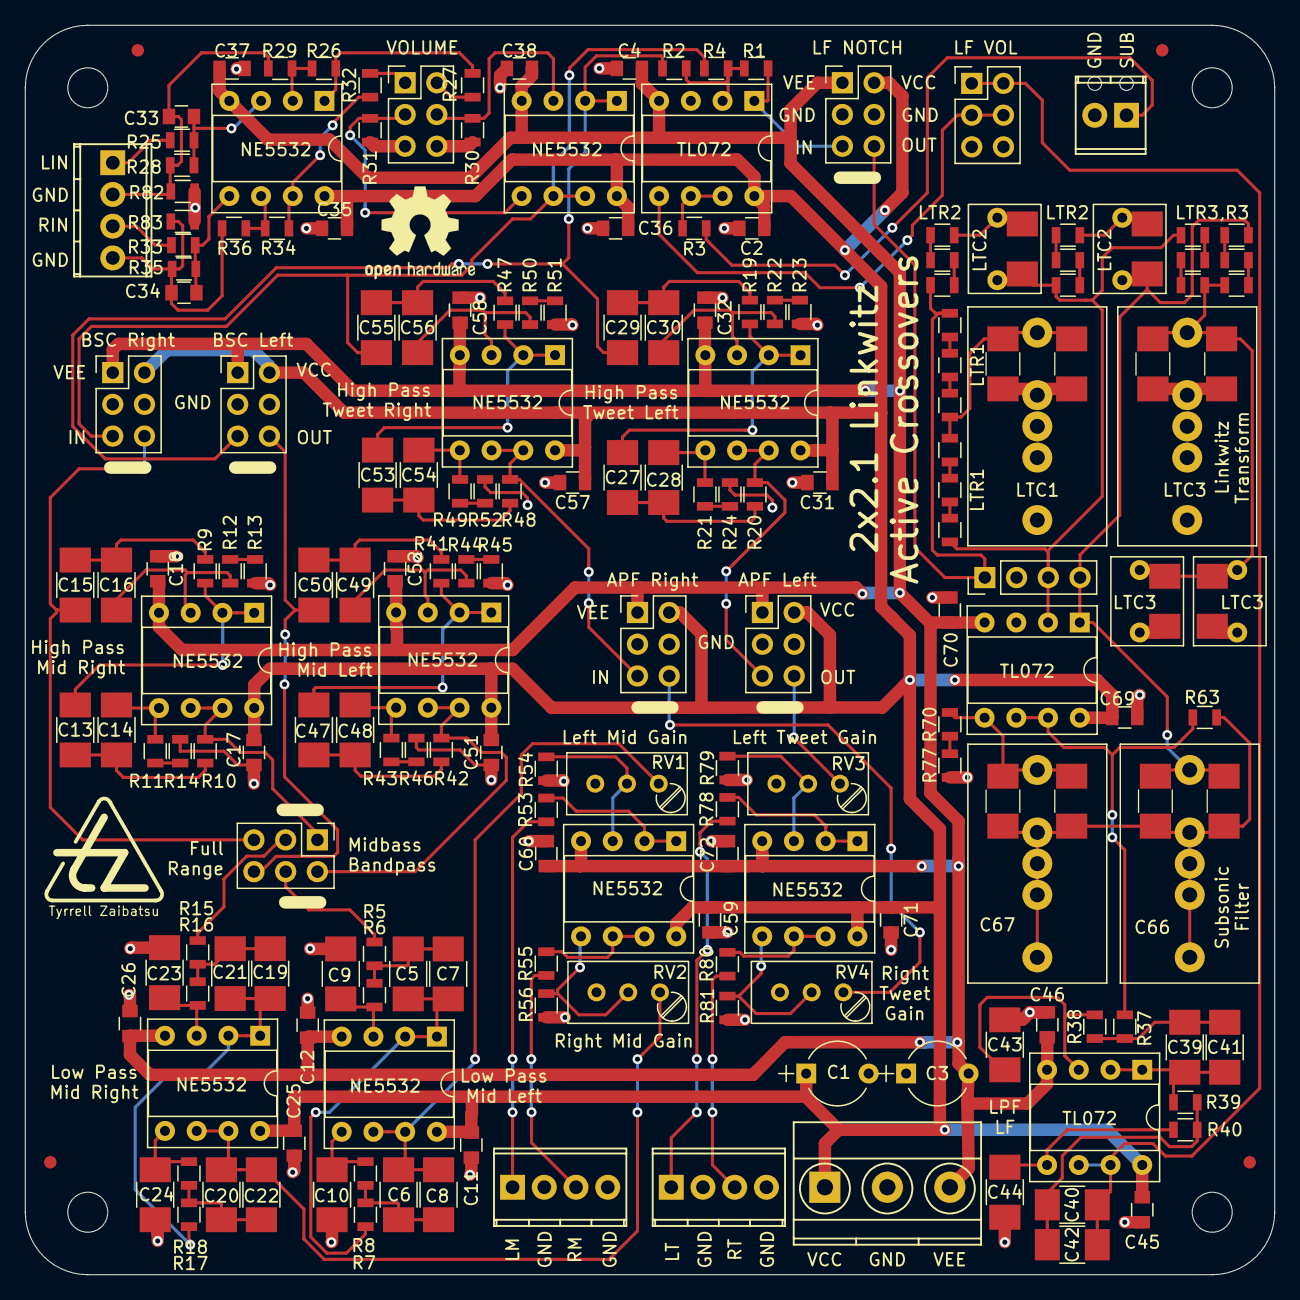
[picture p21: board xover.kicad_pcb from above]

Board: 2 copper layers, 100.0 x 100.0 mm, 194 parts (0 on the bottom side), 115 nets.

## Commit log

2021-10-03 Draft schematic for (2x2).1 crossover system
    [LR4HP.sch, LR4LP.sch, equaliser.sch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]
2021-10-03 Added PDF of schematic
    [LR4HP.sch, inbuf.sch]
2021-10-04 adjusted some caps in PSU and rumble filter
    [psu.sch, xover.sch]
2021-10-04 improved PSU, gain up front, reordered filter stages, shrunk rumble filter
    [LR4HP.sch, LR4LP.sch, equaliser.sch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]
2021-10-05 added buffered volume pot, and fixed subsonic filter added signal taps for external transforms/filters to be added later
    [LR4HP.sch, LR4LP.sch, equaliser.sch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]
2021-10-19 inverted LF processing chain, now with BW2 subsonic filter
    [LR4HP.sch, LR4LP.sch, equaliser.sch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]
2021-10-19 updated schematic PDF
2021-10-20 Board is placed and about half-routed
    [LR4HP.sch, LR4LP.sch, equaliser.sch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]
2021-10-21 completed routing the crossover board
    [xover.kicad_pcb]
2021-10-21 created gerbers
    [xover-B_Cu.gbr, xover-B_Mask.gbr, xover-B_Paste.gbr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]
2021-10-28 polished the layout and taped out
    [xover-B_Paste.gbr, xover-F_Paste.gbr, xover.GBL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]
2021-12-14 updated README to show tested + regulatory
2022-01-21 Rev.B adds "hum break resistor" in input network
    [LR4LP.sch, equaliser.sch, extern.sch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]
2022-04-28 re-plotted with hum-breadk resistors, updated PDF & PNG views
    [xover-B_Cu.gbr, xover-B_Mask.gbr, xover-B_Paste.gbr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]
